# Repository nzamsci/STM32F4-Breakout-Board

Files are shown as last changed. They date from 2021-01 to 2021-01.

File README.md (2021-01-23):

# STM32F405RGT6 Microcontroller Breakout Board
[UNFINISHED] PCB Design based around the STM32F405RGT6 microcontroller. Design includes a 20-pin J-Link debug adapter (SWD), I2C, SPI, and USART interfaces, and a 16 MHz external oscillator.

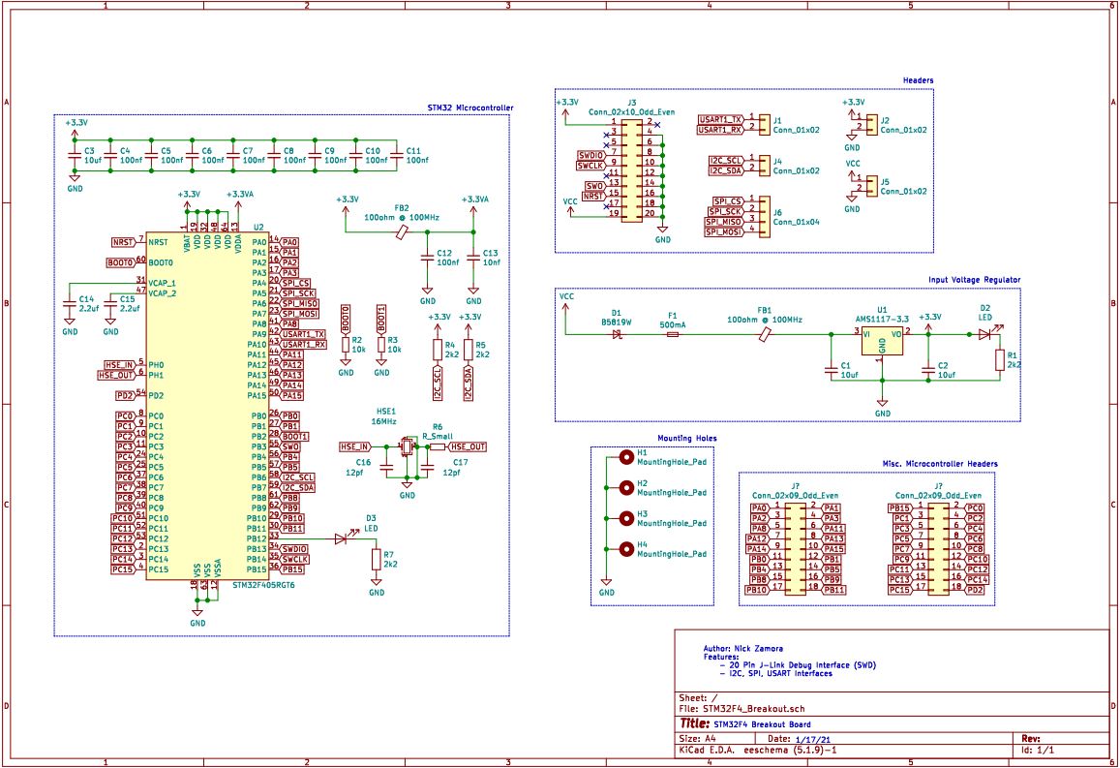
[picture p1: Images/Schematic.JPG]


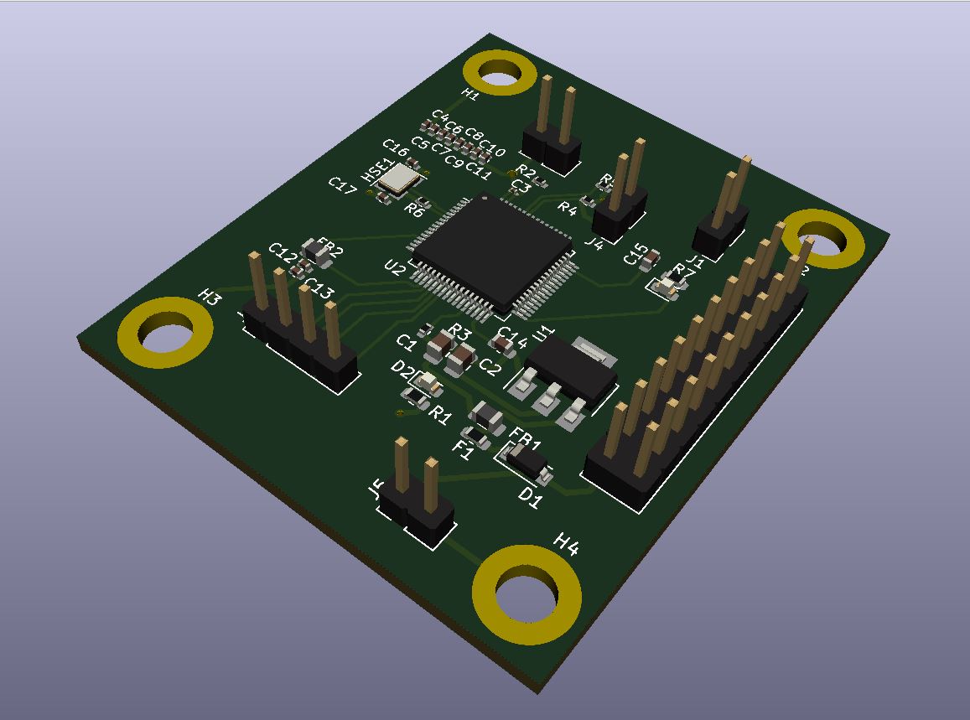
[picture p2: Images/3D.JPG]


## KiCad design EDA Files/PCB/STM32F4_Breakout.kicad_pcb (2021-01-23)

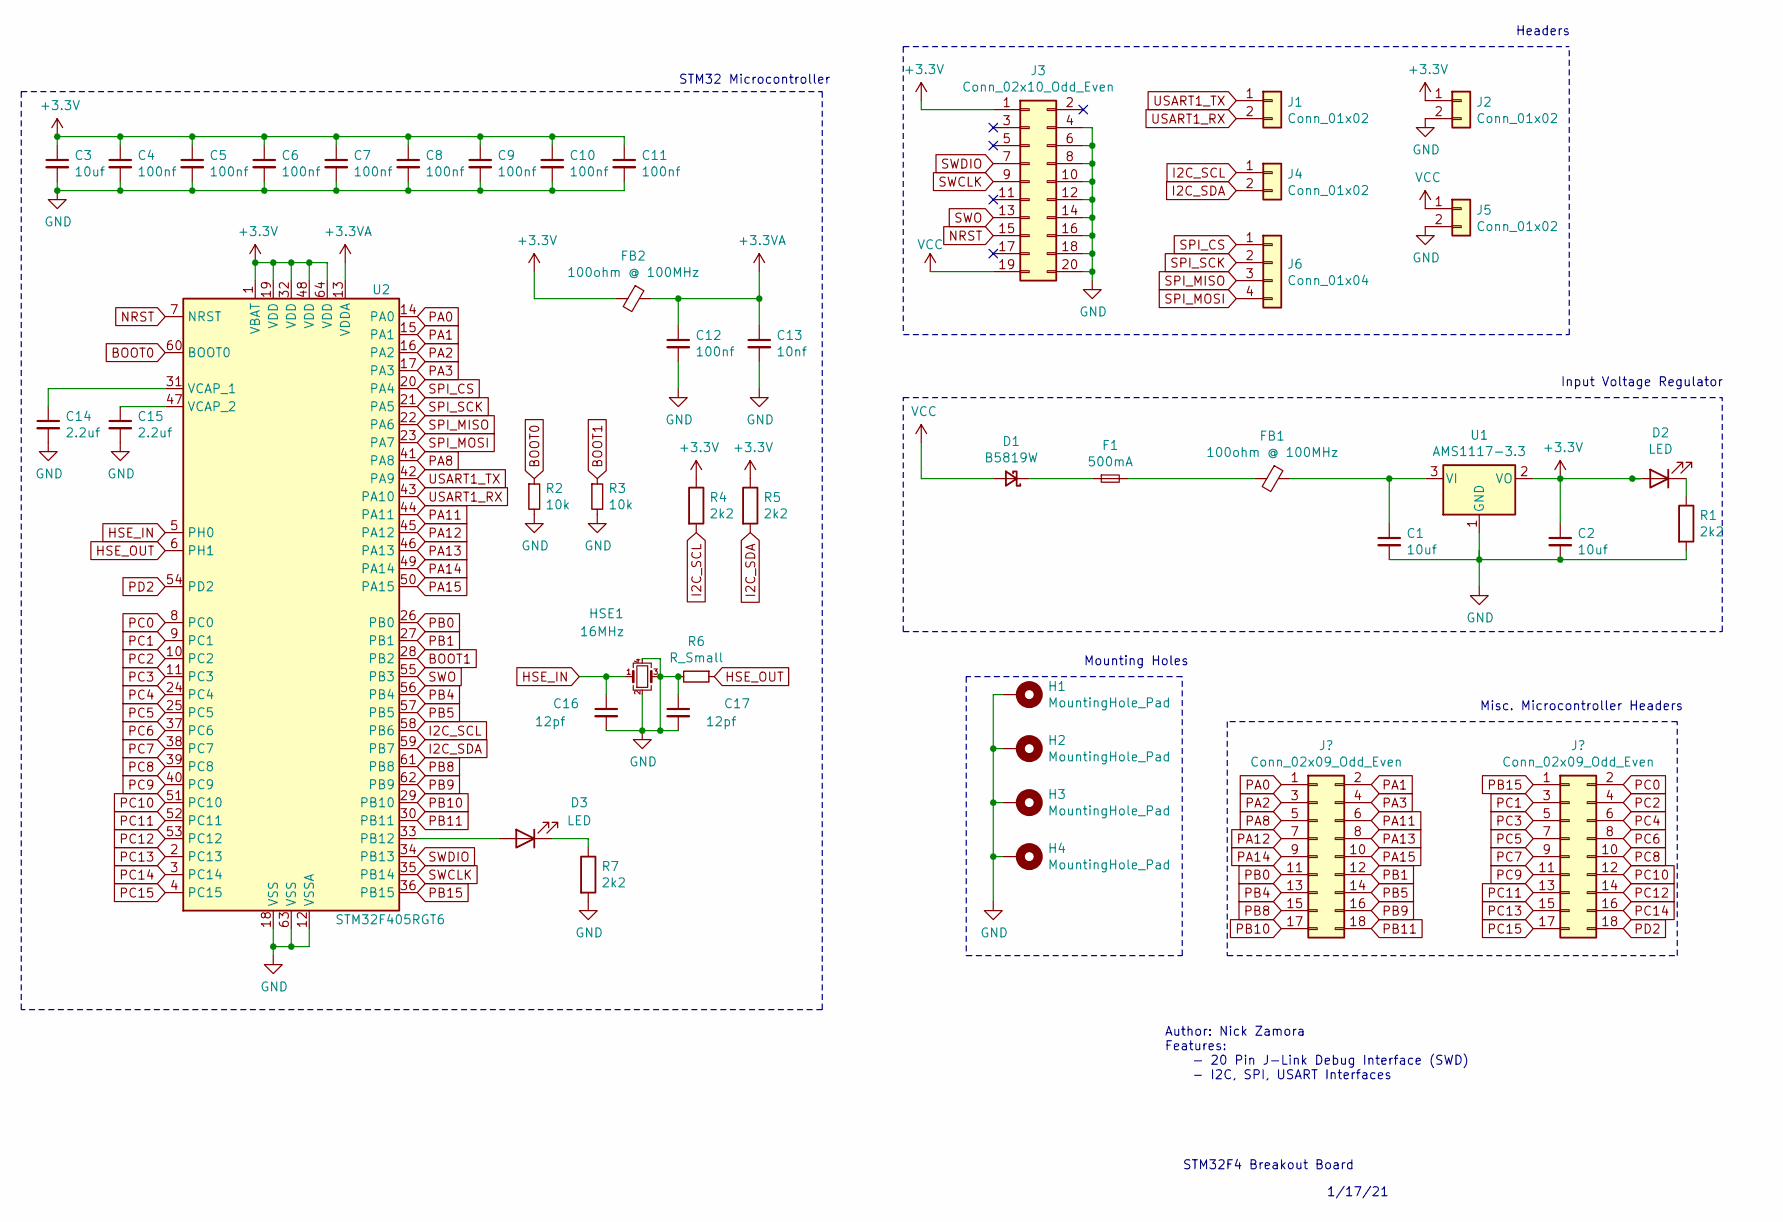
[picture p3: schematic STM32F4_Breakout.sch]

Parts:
C1, C2: 10uf; C_0805_2012Metric
C3: 10uf; C_0201_0603Metric
C4, C5, C6, C7, C8, C9, C10, C11, C12: 100nf; C_0402_1005Metric
C13: 10nf; C_0402_1005Metric
C14, C15: 2.2uf; C_0603_1608Metric
C16, C17: 12pf; C_0402_1005Metric
D1: B5819W; D_SOD-123
D2, D3: LED; LED_0603_1608Metric
F1: 500mA; Fuse_0603_1608Metric
FB1, FB2: 100ohm @ 100MHz; L_0805_2012Metric
H1, H2, H3, H4: MountingHole_Pad; MountingHole_4.3mm_M4_DIN965_Pad
HSE1: 16MHz; Crystal_SMD_3225-4Pin_3.2x2.5mm
J1, J2, J4, J5: Conn_01x02; PinHeader_1x02_P2.54mm_Vertical
J3: Conn_02x10_Odd_Even; PinHeader_2x10_P2.54mm_Vertical
J6: Conn_01x04; PinHeader_1x04_P2.54mm_Vertical
R1, R7: 2k2; R_0603_1608Metric
R2, R3: 10k; R_0402_1005Metric
R4, R5: 2k2; R_0402_1005Metric
R6: R_Small; R_0402_1005Metric
U1: AMS1117-3.3; SOT-223-3_TabPin2
U2: STM32F405RGT6; LQFP-64_10x10mm_P0.5mm

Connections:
+3.3VA: C12.1, C13.1, FB2.1, U2.13 (VDDA)
+3V3: C2.1, C3.1, C4.1, C5.1, C6.1, C7.1, C8.1, C9.1, C10.1, C11.1, D2.2 (A), FB2.2, J2.1, J3.1, R4.1, R5.1, U1.2 (VO), U2.1 (VBAT), U2.19 (VDD), U2.32 (VDD), U2.48 (VDD), U2.64 (VDD)
BOOT0: R2.1, U2.60 (BOOT0)
BOOT1: R3.1, U2.28 (PB2)
HSE_IN: C16.1, HSE1.1, U2.5 (PH0)
HSE_OUT: R6.1, U2.6 (PH1)
I2C_SCL: J4.1, R4.2, U2.58 (PB6)
I2C_SDA: J4.2, R5.2, U2.59 (PB7)
NRST: J3.15, U2.7 (NRST)
unnamed: C1.1, FB1.1, U1.3 (VI)
unnamed: C14.1, U2.31 (VCAP_1)
unnamed: C15.1, U2.47 (VCAP_2)
unnamed: D1.1 (K), F1.1
unnamed: D2.1 (K), R1.1
unnamed: D3.1 (K), R7.1
unnamed: D3.2 (A), U2.33 (PB12)
unnamed: F1.2, FB1.2
PA0: U2.14 (PA0)
PA1: U2.15 (PA1)
PA2: U2.16 (PA2)
PA3: U2.17 (PA3)
PA8: U2.41 (PA8)
PA11: U2.44 (PA11)
PA12: U2.45 (PA12)
PA13: U2.46 (PA13)
PA14: U2.49 (PA14)
PA15: U2.50 (PA15)
PB0: U2.26 (PB0)
PB1: U2.27 (PB1)
PB4: U2.56 (PB4)
PB5: U2.57 (PB5)
PB8: U2.61 (PB8)
PB9: U2.62 (PB9)
PB10: U2.29 (PB10)
PB11: U2.30 (PB11)
PB15: U2.36 (PB15)
PC0: U2.8 (PC0)
PC1: U2.9 (PC1)
PC2: U2.10 (PC2)
PC3: U2.11 (PC3)
PC4: U2.24 (PC4)
PC5: U2.25 (PC5)
PC6: U2.37 (PC6)
PC7: U2.38 (PC7)
PC8: U2.39 (PC8)
PC9: U2.40 (PC9)
PC10: U2.51 (PC10)
PC11: U2.52 (PC11)
PC12: U2.53 (PC12)
PC13: U2.2 (PC13)
PC14: U2.3 (PC14)
PC15: U2.4 (PC15)
PD2: U2.54 (PD2)
SPI_CS: J6.1, U2.20 (PA4)
SPI_MISO: J6.3, U2.22 (PA6)
SPI_MOSI: J6.4, U2.23 (PA7)
SPI_SCK: J6.2, U2.21 (PA5)
SWCLK: J3.9, U2.35 (PB14)
SWDIO: J3.7, U2.34 (PB13)
SWO: J3.13, U2.55 (PB3)
USART1_RX: J1.2, U2.43 (PA10)
USART1_TX: J1.1, U2.42 (PA9)
VCC: D1.2 (A), J3.19, J5.1

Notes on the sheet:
Input Voltage Regulator
STM32 Microcontroller
Mounting Holes
Headers
STM32F4 Breakout Board
Author: Nick Zamora Features: - 20 Pin J-Link Debug Interface (SWD) - I2C, SPI, USART Interfaces
1/17/21
Misc. Microcontroller Headers

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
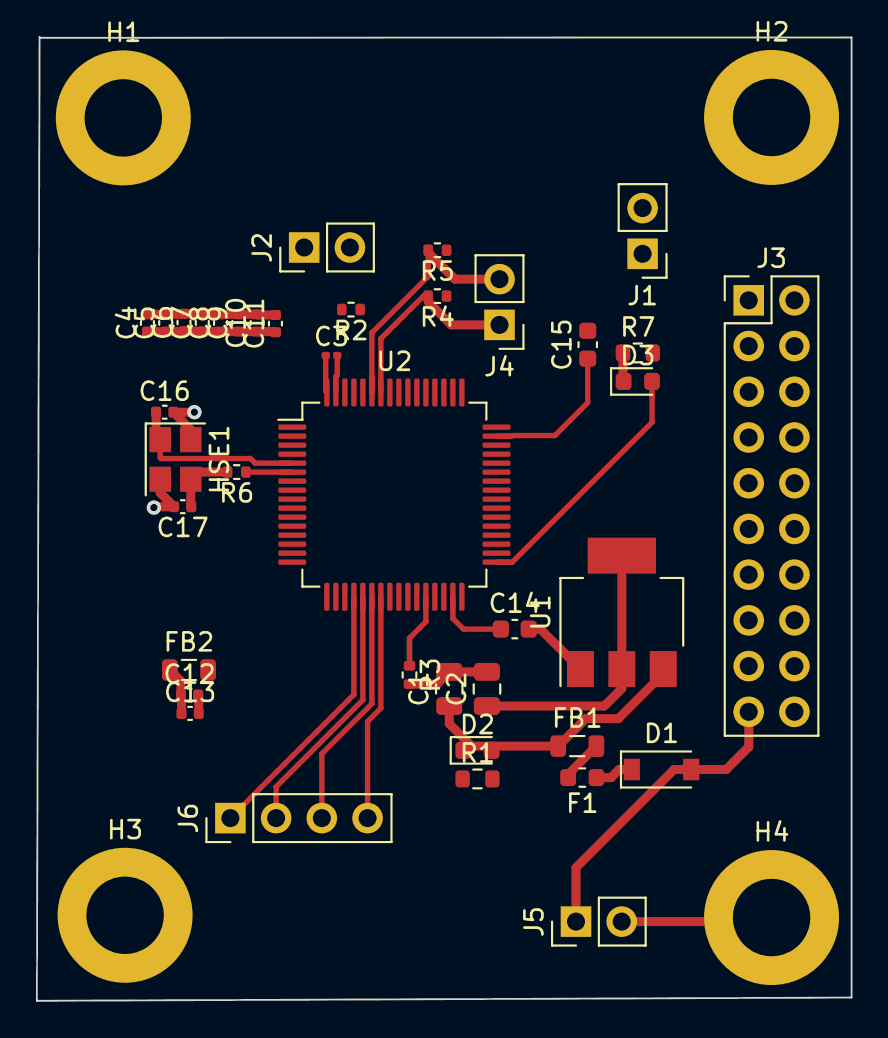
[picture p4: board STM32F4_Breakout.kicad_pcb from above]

Board: 4 copper layers, 45.3 x 53.5 mm, 43 parts (0 on the bottom side), 29 nets.

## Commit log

2021-01-23 Added Schematic
2021-01-23 Updated PCB
    [STM32F4_Breakout.kicad_pcb, STM32F4_Breakout.sch]
2021-01-23 Updated Schematic
